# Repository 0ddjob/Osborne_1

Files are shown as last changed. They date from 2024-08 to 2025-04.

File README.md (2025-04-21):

# Osborne Model 1
## [ROMs](/ROM)
- [2732] Original Osborne BIOS vers. 1.40 (from my Osborne)
- [2732] Original Osborne BIOS vers. 1.43
- [2732] Original Osborne BIOS vers. 1.44 (latest)
- [2732] 3rd party Micro Management OZROM 1E (thanks to user [nelgin](https://forum.vcfed.org/index.php?threads/osborne-1-screen-flash.1245908/post-1400583) on VCFED Forums)
- OZROM manual (cleaned up version thanks to VCFED user booboo)
- [2764] Combined OCC v1.44 & OZROM (requires daughterboard below)
- [2716] Original Osborne character generator ROM (from my Osborne)
- [2716] Original Osborne Screen Pac BIOS Rev. A

Differences between ROM v1.4 and v1.44 include:
```
; CBOOT - added seek 10 tracks and home drive
; GKEY - fixed bell bug
; SENDEN - changed the number of retrys to NRETRY
; PSEKC - added disk head settle delay
; SELDRV - changed start up delay to 500 ms
```
### OCC v1.4 ROM
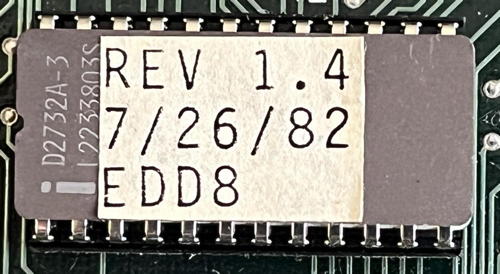
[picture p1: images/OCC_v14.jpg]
Image of OCC v1.40 ROM


### OCC Character Generator ROM
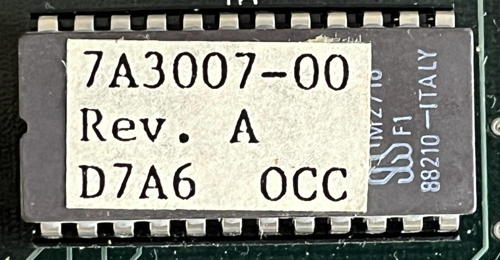
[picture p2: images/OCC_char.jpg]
Image of OCC character ROM


### Micro Management OZROM
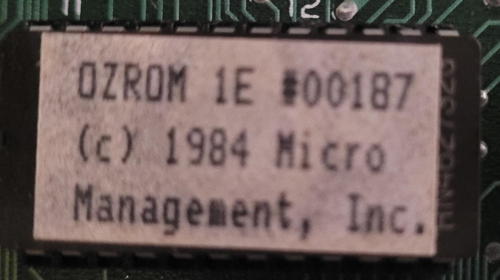
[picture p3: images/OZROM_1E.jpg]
Image of OZROM


## [Daughterboard](/2732-to-2764)
[29-Aug-2024: tested successfully]  
ROM daughterboard to accomodate 28-pin 2764 (8KByte) EPROM in the Osborne's 24-pin 2732 (4KByte) BIOS socket.  Idea is to allow switching between the official Osborne ROM and the 3rd party OZROM.  

Address pin A12 is pulled high by the 10KΩ resistor (so default is upper ROM address range 0x1000 to 0x1FFF) or can be switched to ground via a strapping or switch connected to the A12 pin header (so lower ROM address range 0x0000 to 0x0FFF).

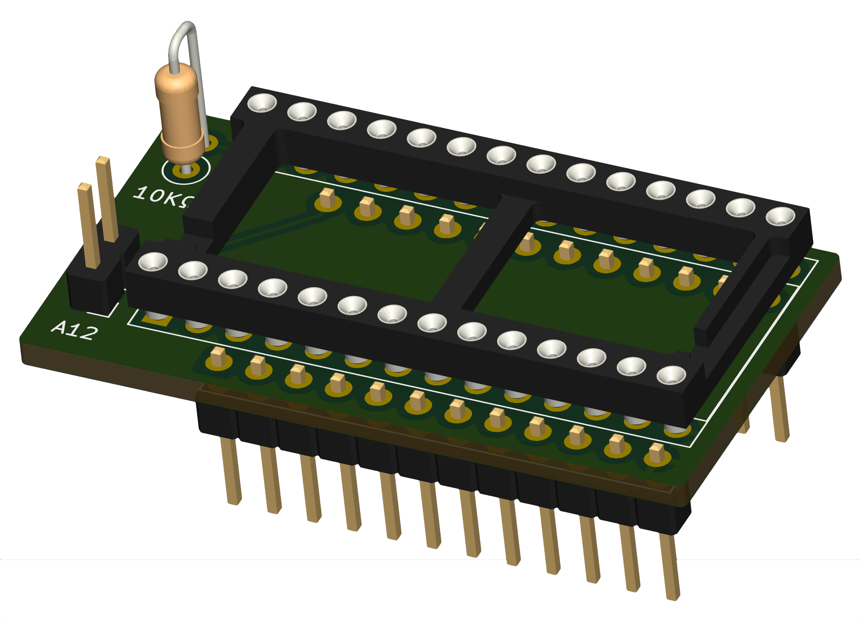
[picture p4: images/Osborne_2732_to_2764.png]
3D image of daughterboard


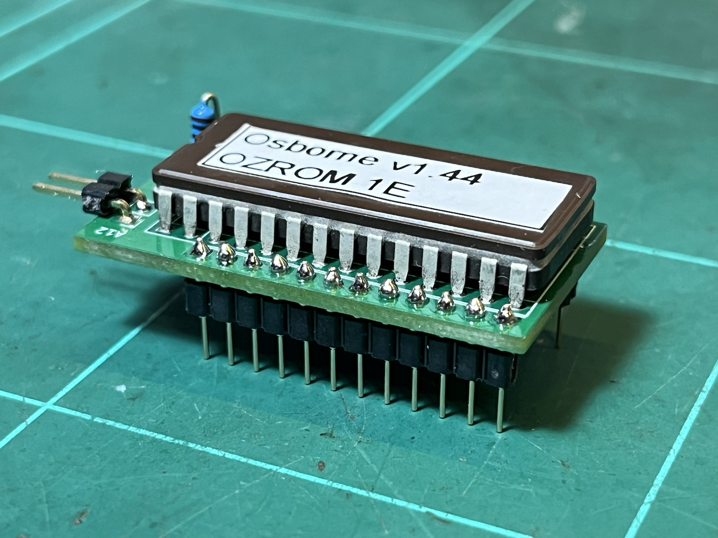
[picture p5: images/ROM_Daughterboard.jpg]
Assembled daughterboard


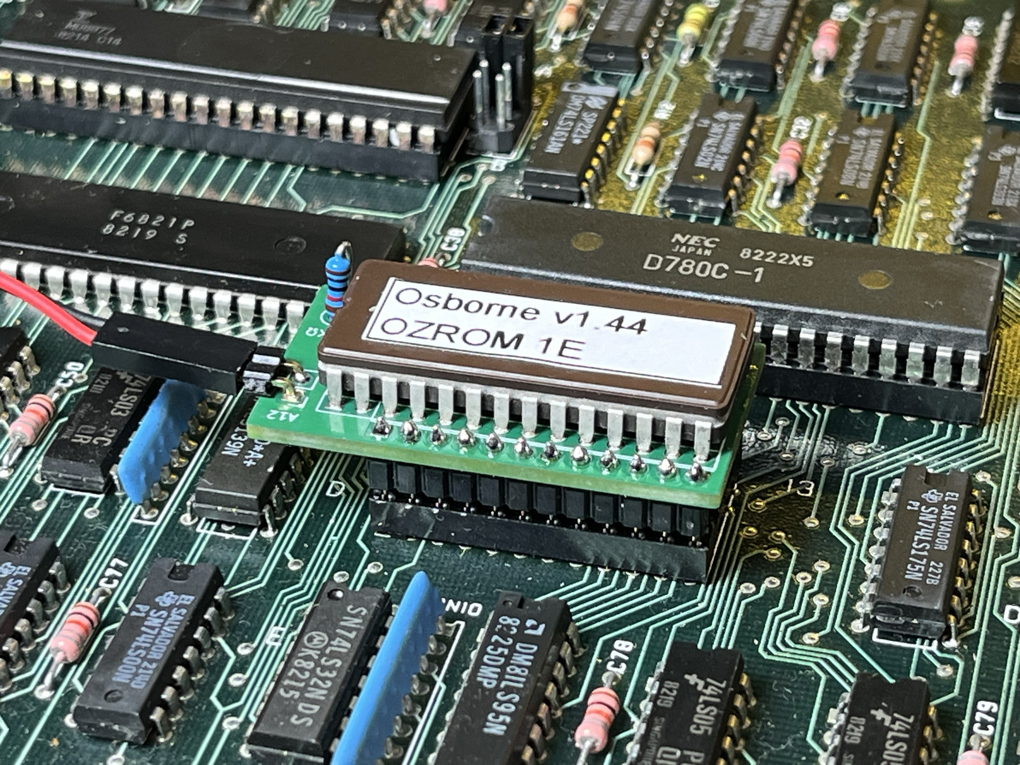
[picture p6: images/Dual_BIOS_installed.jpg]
Installed in Osborne


## [Using A Gotek](/Gotek)
Big thanks to [Dave Dunfield](http://dunfield.classiccmp.org/index.htm) for the original ImageDisk-format (IMD) disk images.

How to tell if an Osborne 1 disk image is single density (SD) or double density (DD)?

Both disk formats have 40 tracks:
* SD disks have ten 256 byte sectors per track (2560 bytes/track) -> 92KByte formatted capacity
* DD disks have five 1024 byte sectors per track (5120 bytes/track) -> 184KByte formatted capacity

Example output of ```fsed.cpm``` info command on an IMG disk image:
```
              Sector length: 1024
           Number of tracks: 40
          Sectors per track: 5
```
## [EXMON Video Output](/EXMON)
Photos of the EXMON video output shunt.

* Sullins MP-0100-10-DS-4 card edge connector
* Hyko K688-DI - this appears to combine horizontal & vertical sync with the video output, powered by +12V

Pinout of EXMON

## [Double Density Upgrade](/DD_Upgrade)
Photos of the original Osborne DD upgrade board and details of a modern reproduction board.

## [Screen Pac Upgrade](/Screen_Pac/)
Photos of the Screen Pac board.

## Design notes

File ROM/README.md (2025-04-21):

- [2716] Osborne character generator ROM (from my Osborne)
- [2716] Osborne Screen Pac BIOS Rev. A
- [2732] Osborne BIOS vers. 1.40 (from my Osborne)
- [2732] Osborne BIOS vers. 1.43 (from a DD-upgraded motherboard)
- [2732] Osborne BIOS vers. 1.44 (latest)
- [2732] 3rd Party Micro Management OZROM 1E (thanks to user [neglin](https://forum.vcfed.org/index.php?threads/osborne-1-screen-flash.1245908/post-1400583) on VCFED Forums)
- [2764] Combined OCC v1.44 & OZROM (would require a daughterboard & switch)

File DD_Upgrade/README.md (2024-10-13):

# Osborne Model 1 Double Density Upgrade
## Modern Reproduction
[Nathaniel Roach's reproduction DD board](https://gitlab.com/NRoach44/occ1-dd-upgrade)<br>
[VCFED Forum post](https://forum.vcfed.org/index.php?threads/reproduction-osborne-1-dd-upgrade-card.1239167/)

## Images of Osborne board
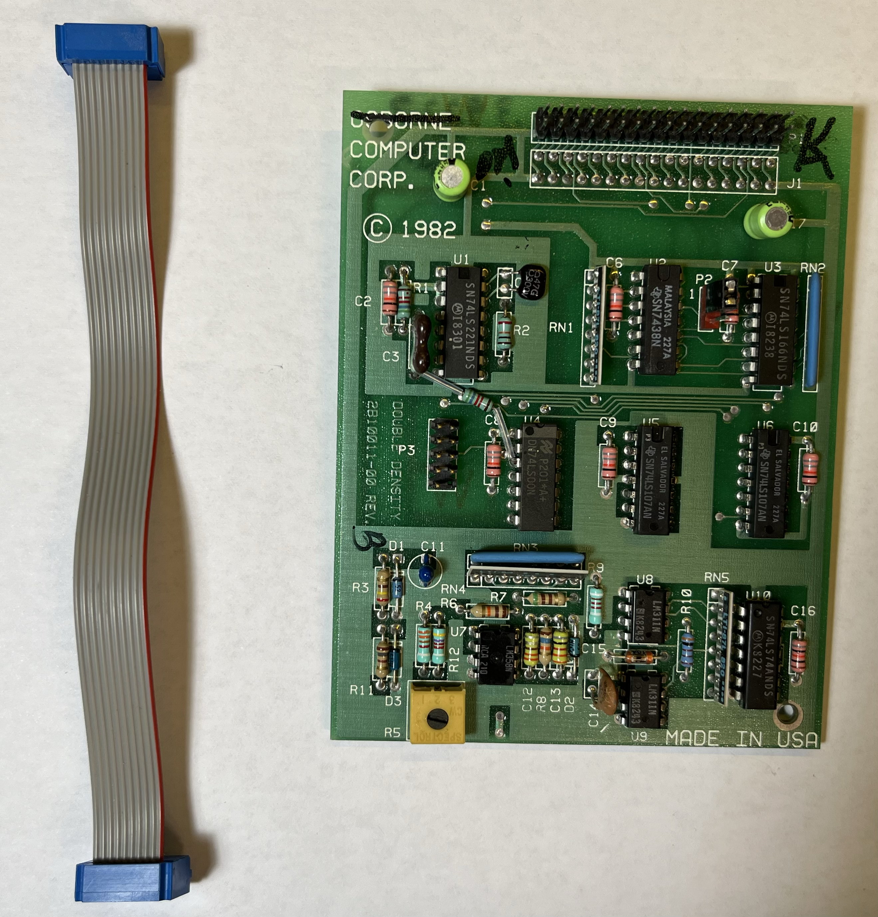
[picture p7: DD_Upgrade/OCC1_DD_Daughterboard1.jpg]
Daughterboard_1

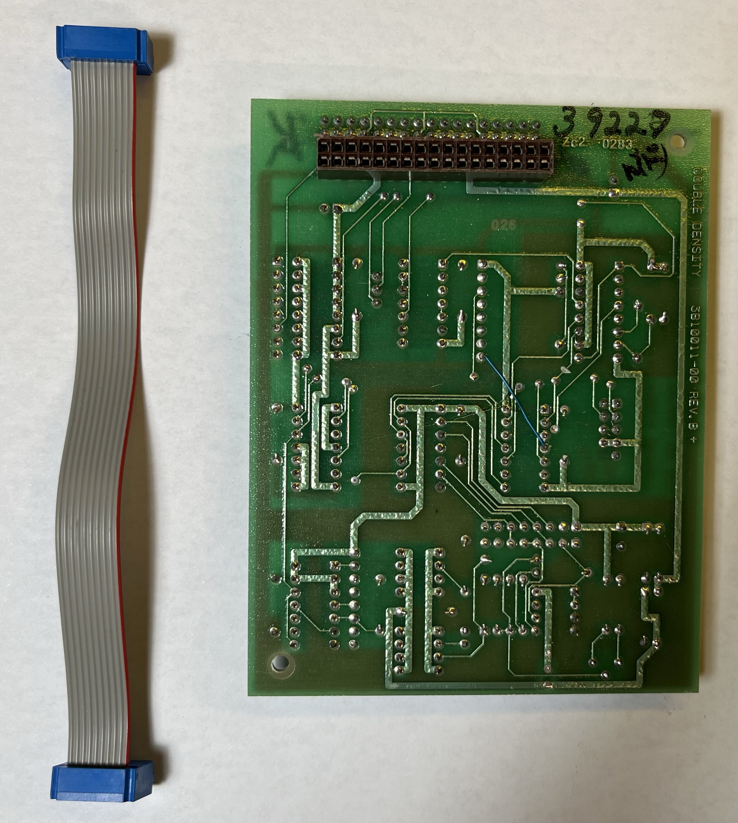
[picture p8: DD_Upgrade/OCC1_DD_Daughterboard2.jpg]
Daughterboard_2

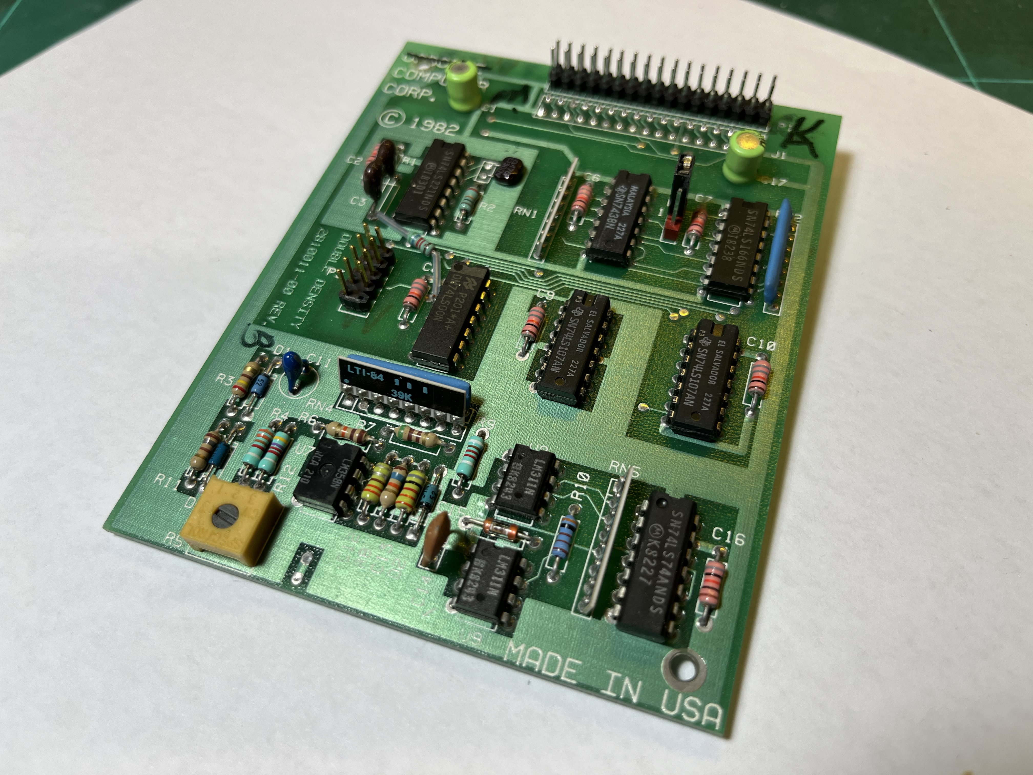
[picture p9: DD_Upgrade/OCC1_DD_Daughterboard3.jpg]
Daughterboard_3

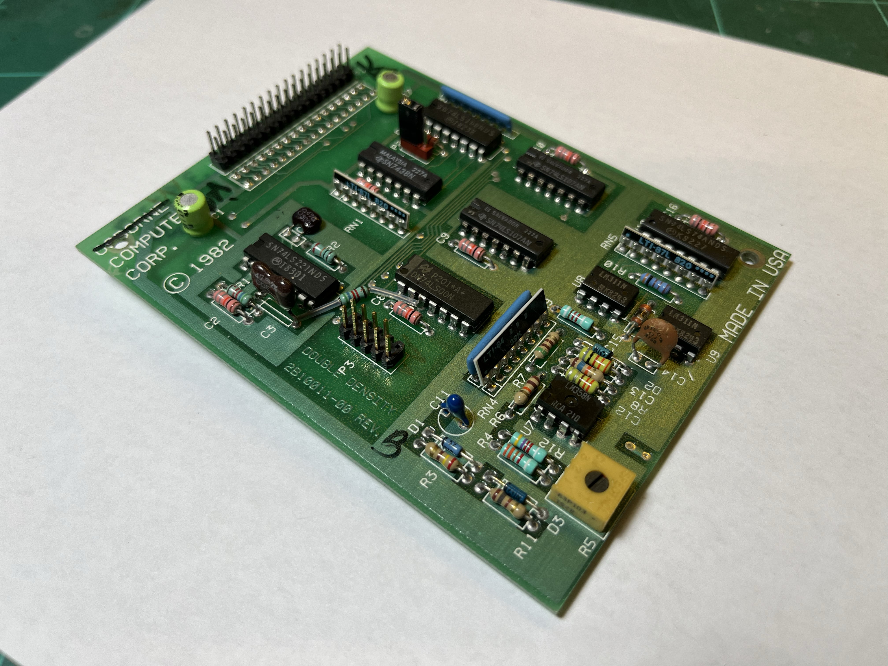
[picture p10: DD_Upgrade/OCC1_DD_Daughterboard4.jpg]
Daughterboard_4

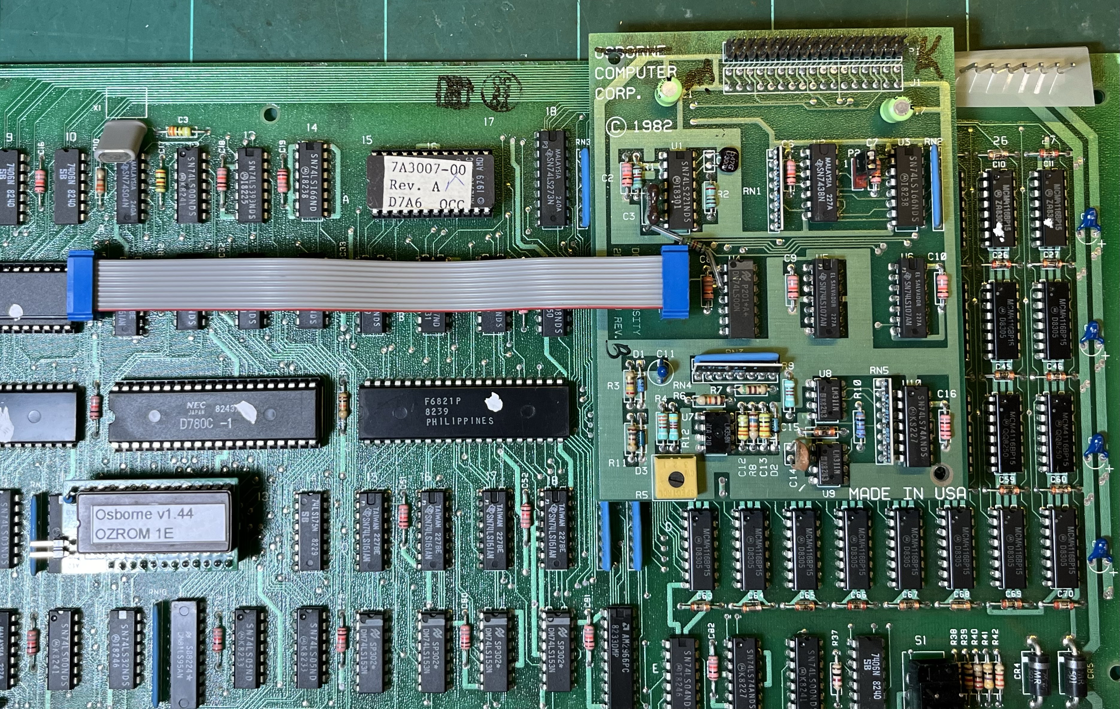
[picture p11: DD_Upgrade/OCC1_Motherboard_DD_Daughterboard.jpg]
Motherboard & Daughterboard

Note that the ribbon cable has ten wires but only eight are needed (2x4), so the cable is keyed to ensure it's installed correctly.
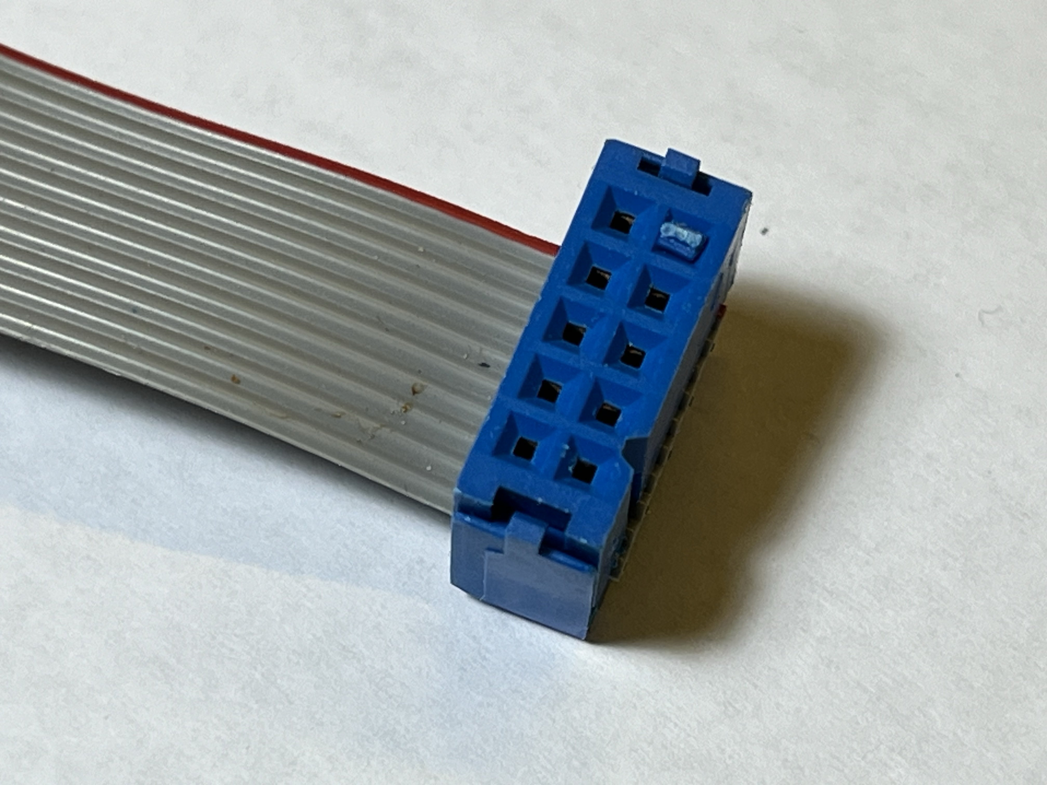
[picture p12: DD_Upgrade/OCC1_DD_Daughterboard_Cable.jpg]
Daughterboard cable


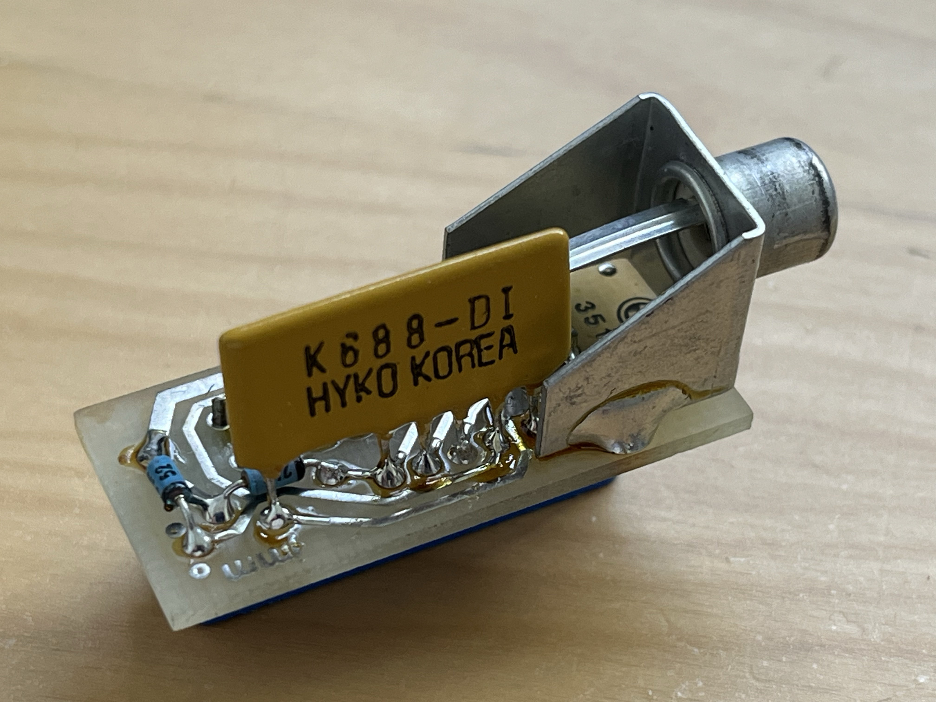
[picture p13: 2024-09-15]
EXMON/EXMON_3.jpg

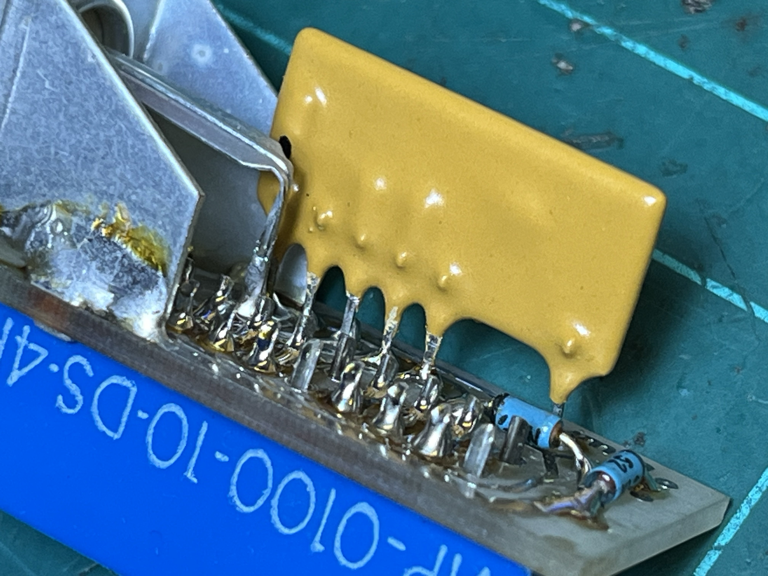
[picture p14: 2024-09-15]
EXMON/EXMON_8.jpg

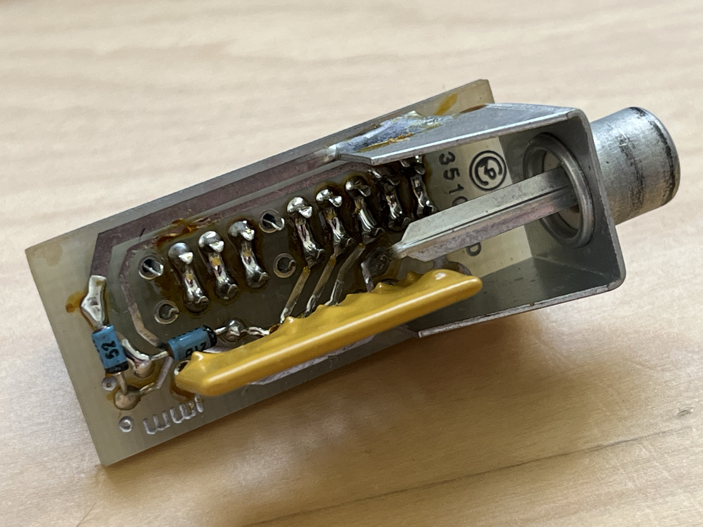
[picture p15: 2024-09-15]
EXMON/EXMON_5.jpg

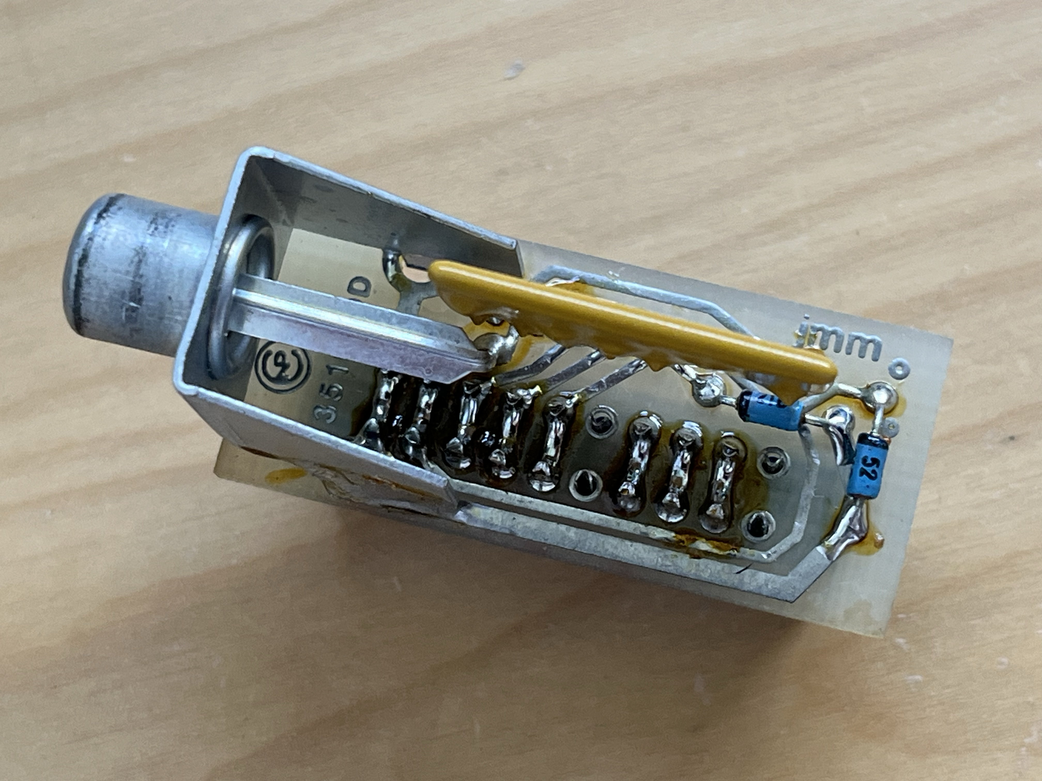
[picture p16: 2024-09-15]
EXMON/EXMON_4.jpg

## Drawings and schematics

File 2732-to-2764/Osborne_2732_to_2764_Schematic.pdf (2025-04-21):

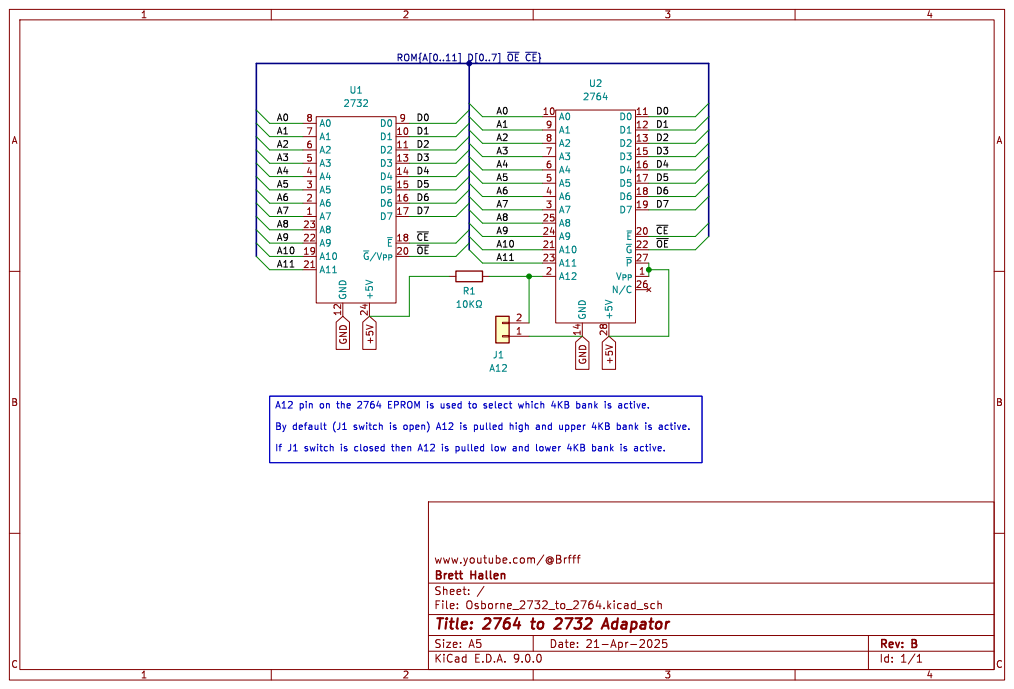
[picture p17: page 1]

If J1 switch is closed then A12 is pulled low and lower 4KB bank is active.

www.youtube.com/@Brfff
Sheet: /
File: Osborne_2732_to_2764.kicad_sch
Title: 2764 to 2732 Adapator

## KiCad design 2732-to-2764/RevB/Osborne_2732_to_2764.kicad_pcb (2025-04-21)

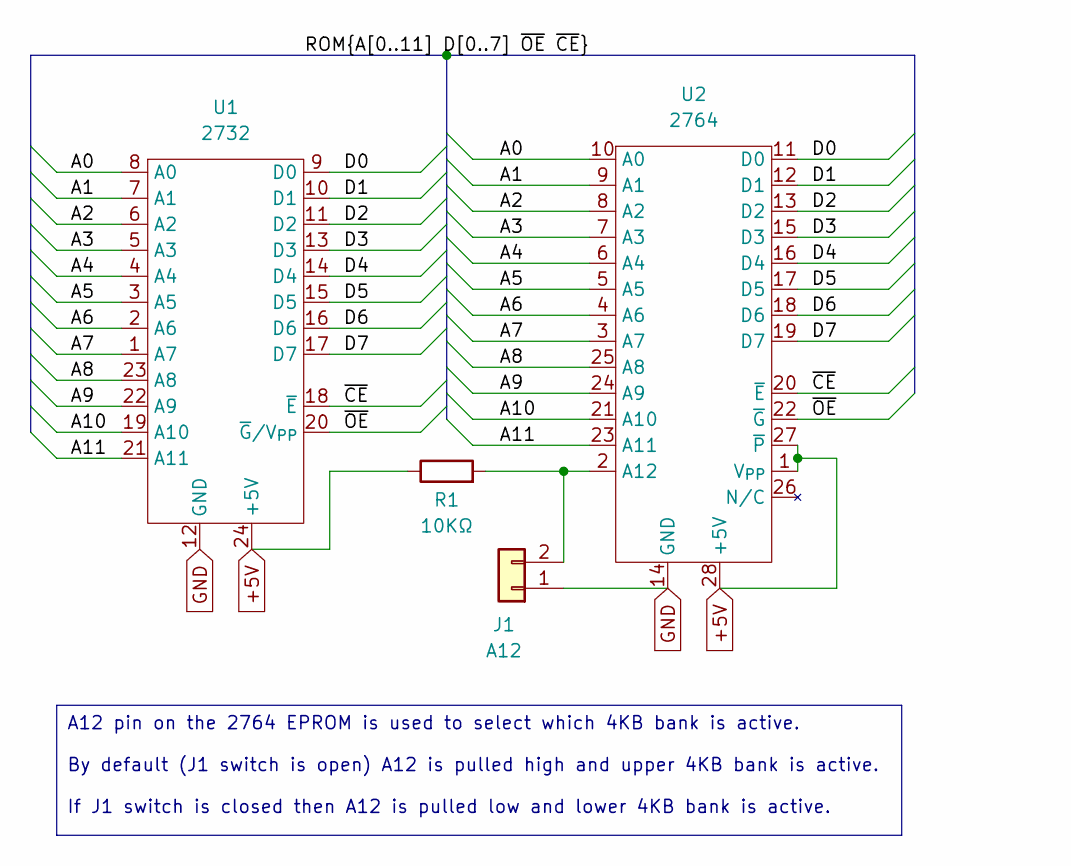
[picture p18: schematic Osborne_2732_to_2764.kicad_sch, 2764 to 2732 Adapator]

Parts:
J1: A12; PinHeader_1x02_P2.54mm_Vertical
R1: 10KΩ; R_Axial_DIN0207_L6.3mm_D2.5mm_P2.54mm_Vertical
U1: 2732; DIP-24_W15.24mm-Notch
U2: 2764; DIP-28_W15.24mm_Socket

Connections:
+5V: R1.1, U1.24 (+5V), U2.1 (V_{PP}), U2.27 (~P), U2.28 (+5V)
/A0: U1.8 (A0), U2.10 (A0)
/A1: U1.7 (A1), U2.9 (A1)
/A2: U1.6 (A2), U2.8 (A2)
/A3: U1.5 (A3), U2.7 (A3)
/A4: U1.4 (A4), U2.6 (A4)
/A5: U1.3 (A5), U2.5 (A5)
/A6: U1.2 (A6), U2.4 (A6)
/A7: U1.1 (A7), U2.3 (A7)
/A8: U1.23 (A8), U2.25 (A8)
/A9: U1.22 (A9), U2.24 (A9)
/A10: U1.19 (A10), U2.21 (A10)
/A11: U1.21 (A11), U2.23 (A11)
/D0: U1.9 (D0), U2.11 (D0)
/D1: U1.10 (D1), U2.12 (D1)
/D2: U1.11 (D2), U2.13 (D2)
/D3: U1.13 (D3), U2.15 (D3)
/D4: U1.14 (D4), U2.16 (D4)
/D5: U1.15 (D5), U2.17 (D5)
/D6: U1.16 (D6), U2.18 (D6)
/D7: U1.17 (D7), U2.19 (D7)
/~CE: U1.18 (~E), U2.20 (~E)
/~OE: U1.20 (~G/V_{PP}), U2.22 (~G)
GND: J1.1, U1.12 (GND), U2.14 (GND)
unnamed: J1.2, R1.2, U2.2 (A12)

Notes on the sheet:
A12 pin on the 2764 EPROM is used to select which 4KB bank is active. By default (J1 switch is open) A12 is pulled high and upper 4KB bank is active. If J1 switch is closed then A12 is pulled low and lower 4KB bank is active.

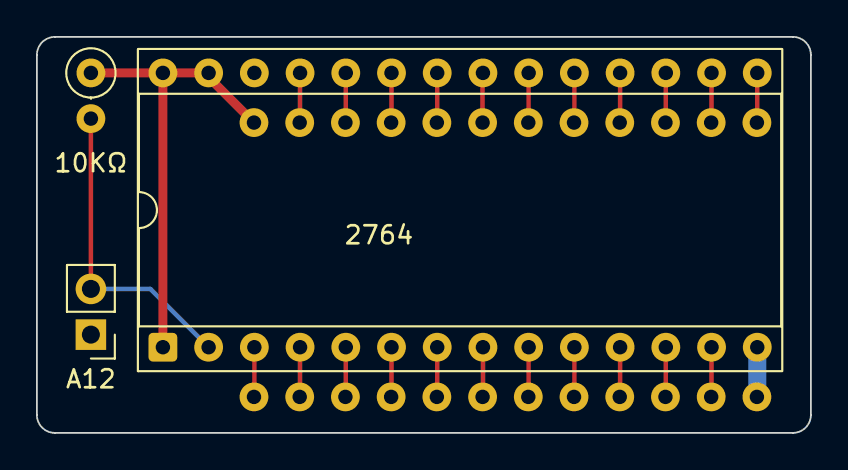
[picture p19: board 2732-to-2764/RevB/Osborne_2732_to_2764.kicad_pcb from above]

Board: 2 copper layers, 43.0 x 22.0 mm, 4 parts (0 on the bottom side), 25 nets.

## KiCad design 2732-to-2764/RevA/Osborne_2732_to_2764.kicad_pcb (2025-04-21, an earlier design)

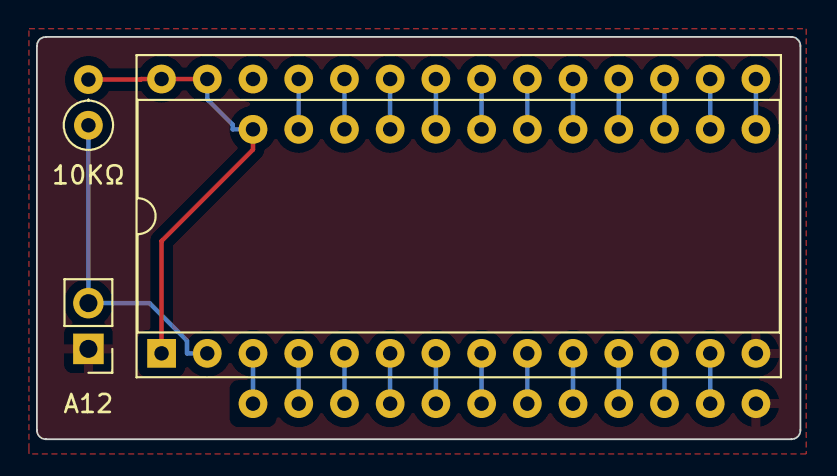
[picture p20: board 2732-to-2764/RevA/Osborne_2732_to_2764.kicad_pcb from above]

Board: 2 copper layers, 42.4 x 22.4 mm, 4 parts (0 on the bottom side), 25 nets.

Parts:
J1: 2732_ROM_Socket; DIP-24_W15.24mm-Notch
J2: 2764; DIP-28_W15.24mm_Socket
J3: A12; PinHeader_1x02_P2.54mm_Vertical
R1: 10KΩ; R_Axial_DIN0207_L6.3mm_D2.5mm_P2.54mm_Vertical

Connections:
A00: J1.8, J2.10
A01: J1.7, J2.9
A02: J1.6, J2.8
A03: J1.5, J2.7
A04: J1.4, J2.6
A05: J1.3, J2.5
A06: J1.2, J2.4
A07: J1.1, J2.3
A08: J1.23, J2.25
A09: J1.22, J2.24
A10: J1.19, J2.21
A11: J1.21, J2.23
D0: J1.9, J2.11
D1: J1.10, J2.12
D2: J1.11, J2.13
D3: J1.13, J2.15
D4: J1.14, J2.16
D5: J1.15, J2.17
D6: J1.16, J2.18
D7: J1.17, J2.19
GND: J1.12, J2.14, J3.1
unnamed: J2.2, J3.2, R1.1
VCC: J1.24, J2.1, J2.27, J2.28, R1.2
~CE: J1.18, J2.20
~OE: J1.20, J2.22

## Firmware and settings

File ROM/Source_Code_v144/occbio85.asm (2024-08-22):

 	page


; The following routines will use the IOBYTE to transfer 
; control to the appropriate device driver

CONST:
;	Returns console status

	proc
	LDK	HL,PTR_CSTAT	;Status table
	JR	GODISPCH	;Call appropriate rtn
	space 4,7
CONIN:
;	Reads input character from device

	proc
	LDK	HL,PTR_CINP	;Table of input rtns
	JR	GODISPCH
	space 4,8
CONOUT:
;	Puts output character to device
;	C contains output character

	proc
	LDK	HL,PTR_COUT	;Table of output rtns
	space 4,7
GODISPCH:
	LDK	B,1		;number of shifts required to align
				;CONSOLE field
	JR	DISPCH
	space 4,20
LIST:
;	List device character output

	proc
	LDK	HL,PINTFG	;Get printer initialiation flag
	LD	A,[HL]
	ORA	A
	JRNZ	LIST1		;Printer previously initialized

	DEC	[HL]		;Non-zero value to PINTFG
	PUSH	BC		;Save character
	INC	HL
	EX	HL,DE		;Get initialization string
	CALL	PSTR		;and print it
	POP	BC		;Restore character

LIST1: 	LDK	B,4
Š	LDK	HL,PTR_LIST	;table of list routines
	JR	DISPCH
	space	4,8
PUNCH:
;	Output to punch

	proc
	LDK	B,6
	LDK	HL,PTR_PNCH	;Punch routines
	JR	DISPCH
	space	4,8
READER:
;	Reader input

	proc
    	LDK	B,8
	LDK	HL,PTR_RDR	; reader routines
	JR	DISPCH
	space	4,14
LISTST:
;	Return the ready status for the list device.
;
;	EXIT	A = 0 (zero), list device is not ready to
;		accept another character.
;		A = FFh (255), list device is ready to accept
;		a character.

	proc
	LDK	B,4		;number of left shifts thru carry
				;to align LIST field of IOBYTE
	LDK	HL,PTR_LST	;list status routines
;	JR	DISPCH
	page

DISPCH:
;	on entry here reg B contains the left shift count
;	required to align the iobyte field to bit 1 position.
;	and reg HL contains address of select table

	proc
	LD	A,IOBYTE

DSPCH1:
	RAL
	DJNZ	DSPCH1
	ANI	6		;get select field*2
	MOV	E,A
	LDK	D,0		;DE = iobyte field * 2
	DAD	DE
	MOV	E,[HL]
Š	INC	HL
	MOV	H,[HL]		;get the routine address
	MOV	L,E		;into hl and xchange with pc
	JMP	[HL]
	PAGE

;	Dispatch Table

PTR_CSTAT:
	DW	CNST		; keyboard status
	DW	SISTAT		; serial port input status
	DW	PISTAT		; parallel input status
	DW	IEINSTAT	; status of input device on IEEE port

PTR_RDR:
PTR_CINP:
	DW	KEYINP		; get input from keyboard
	DW	SPINP		; serial port input
	DW	PARINP		; parallel input
	DW	IEINP		; ieee port input

PTR_PNCH:
PTR_COUT:
	DW	CRTOUT		; output character to crt
	DW	SPOUT 		; serial port output
	DW	PAROUT		; parallel output
	DW	IEOUT		; ieee port output

PTR_LST:
	DW	CRSTAT
	DW	SOSTAT		; serial output status
	DW	POSTAT		; parallel output status
	DW	IEOSTAT		; ieee output status

PTR_LIST:
	DW	CRTOUT
	DW	PRTOUT
	DW	PAROUT
	DW	IEOUT
	page

CNST:
;	C O N S O L   S T A T U S
;
;	This routine samples the Console status and returns the
;	following values in the A register.
;
;	EXIT	A = 0 (zero), means no character
;		currently ready to read.
;
;		A = FFh (255), means character
;		currently ready to read.

;	check if any translated keys are pending

	proc
	LD	A,COUNT
	ORA	A
	JRNZ	CNST5

;	if no xlated keys pending, check keyhit flag
Š
	LD	A,LKEY		;Get Key hit flag
	ORA	A
	RZ			;If data not available

CNST5:
	ORI	0FFh
	RET
	page

KEYINP:
; 	Gets keystroke from ROM keyboard driver.
;	Translates the codes 80h to 8fh as per table. 
;
; 	EXIT	 A = translated code in ASCII

BASVL0:	=	80h			;lowest value of translatable keys
	proc
	PUSH	IX			;Save user IX

KIN0:	CALL	AHSCRL
	LDK	HL,COUNT
	LD	A,[HL]			;get number of xlated keys
	ORA	A
	JRZ	KIN10			;if keys pending then
	LD	IX,XLTKEY		;get base address in IX reg

	LD	A,[IX+0]		;simulate LD  A,(IX+COUNT)
COUNT:	=	*-1			;to get next key from table

	INC	[HL]			;increment count

KRET:	POP	IX			;Restore user IX
	RET

KIN10:
	LDK	E,09
	CALL	ROMCD1

;	When console has returned this code will check
;	for function key and preform some translation

	CPI	80h		;function keys have value
	JRC	KRET		;80h-8dh
	CPI	8Eh		;do a shift to make pointer 
	JRNC	KRET		;into table and return if not function key
	SLA	A
	MOV	E,A
	LDK	D,0
	LDK	IX,XLTBL
	ADD	IX,DE
 	LD	L,[IX+0]
	LD	H,[IX+1]
	LD	E,[IX+2]
	LD	D,[IX+3]
	STO	DE,XLTKEY
Š	SBC	HL,DE
	MOV	A,L
	STO	A,COUNT
	JR	KIN0
        page

AHSCRL:
;	ahscrl - does auto horizontal scroll if required.

	proc
	LD	A,AHSENB
	OR	A
	RZ

	LD	HL,CURS		;get cursor
	ADD	HL,HL

;	check for cursor in home window

	LDK	A,100
	CMP	L
	JRC	RHC		;jump if cursor not in home window
	LD	A,PIAAD		;check for screen at home
	SUB	VFLO
	RZ			;screen at home
	XRA	A		;home screen
	JR	SCRL

RHC:
;	check right-hand margin

	LD	A,PIAAD		;a=horizontal screen position
	SUB	VFLO
	ADD	A,100		;window size*2 (50)
	CMP	L
	JC	:30		;move screen when cursor about to go off
				;the right hand margin
;	check left hand margin

	SUB	90
	CMP	L		;check left margin
	RC			;cursor in window return
	MOV	A,L
	SUB	10
	RZ			;return if cusor at column 2
	JR	SCRL

:30:	MOV	A,L
	SUB	100

SCRL:	RAR
	ADD	A,' '
	LK	HL,ESCSQ+3
	STO	A,[HL]
	LD	A,PIABD
	AND	1Fh
	ADD	A,' '
	DEC	HL
	STO	A,[HL]			;escsq+2 = vert. coords
	DEC	HL
	DEC	HL			;point to start of esc seq
	LK	B,4

:50:	PUSH	BC
Š	PUSH	HL
	LD	C,[HL]
	CALL	CRT10
	POP	HL
	POP	BC
	INC	HL
	DJNZ	:50	
	RET	

ESCSQ:	DB	ESC			;set screen coord escape sequence
	DB	'S'
	DB	0			;** y coord
	DB	0			;** x coord
	page

CRSTAT:
;	Returns status of crt.
;	crt is always ready

	proc
	ORI	0FFh
	RET
	space	4,10
CRTOUT:
;	ENTRY	 C = output character

EF_ESC:	=	8		;escape flag bit definitions
EF_GR:	=	1

	proc
	LD	A,ESCH
	AND	EF_ESC+EF_GR
	JRNZ	CRT10
	MOV	A,C
	CPI	14h
	JRNZ	CRT10
	LD	A,AHSENB
	CMA
	STO	A,AHSENB
	RET

CRT10:
	LDK	E,0Ch		  ;output to crt
	JMP	ROMCD1
	page

SOSTAT:
;	Gets status of output device attached to serial port

	proc
	LDK	E,2Dh
	JR	JMPROM		;Call rom driver
	space 4,8
SISTAT:
;	Gets status of input device attached to serial port

	proc
	CALL	ACISTAT
	ANI	SI.RRDY
	RZ			;return with not ready status
	ORI	TRUE
	RET
	space 4,8
SPINP:
;	Inputs a character from the serial port 

	proc
	LDK	E,15h
	JR	JMPROM
	space 4,8
SPOUT:
;	Outputs character in reg c to the serial port (list device)

	proc
	LDK	E,0Fh
	JR	JMPROM
	page

PRTOUT:
;	routine does LIST output and printer protocols

XON:	=	11h
XOFF:	=	13h
ETX:	=	3
ACK:	=	6

	proc
	CALL	SPOUT
	LD	A,PRNTER
	ORA	A
	RZ
	ANI	2
	JRNZ	XONXOF
	LDK	A,0Dh
	CMP	C
	RNZ

	LDK	C,ETX
	CALL	SPOUT

PRT10:
	CALL	SPINP
	ANI	7Fh		;mask out parity bit
	CPI	ACK
	JRNZ	PRT10
	RET

XONXOF:
	CALL	SISTAT
	ORA	A
	RZ
	CALL	SPINP
	ANI	7Fh		;mask out parity bit
	CPI	XOFF
	RNZ

PRT20:
	CALL	SPINP
	ANI	7Fh		;mask out parity bit
	CPI	XON
	JRNZ	PRT20
	RET
	PAGE

JMPROM:	JMP	ROMCD1
	space	4,10
ACICTL:	=	SBAUD
;	Outputs character in c to the ACIA CTL port.
	space	4,10
ACISTAT:
;	Returns usart status in A
	
	PROC
	LDK	E,81H		;Low order byte of ACISTAT routine in ROM
	JR	JMPROM	
	page
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

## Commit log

2024-08-19 Added FF configuration files for simplicity
    [FF.CFG, IMG.CFG]
2024-08-19 Intial 2764 adaptor design
    [Osborne_2732_to_2764.kicad_pcb, Osborne_2732_to_2764.kicad_sch]
2024-08-19 Corrected subdirectory name
    [Osborne_2732_to_2764.kicad_pcb, Osborne_2732_to_2764.kicad_sch]
2024-08-19 Updated silkscreen
    [Osborne_2732_to_2764.kicad_pcb]
2024-08-21 Corrected Gerbers for PCBWAY (still pending testing)
    [Osborne_2732_to_2764.kicad_pcb]
2024-08-23 Updated socket pins
    [Osborne_2732_to_2764.kicad_pcb, Osborne_2732_to_2764.kicad_sch]
2024-09-15 Soldered EPROM directly to daughterboard
2024-09-15 Further device detail
2024-11-25 Updated to Kicad 8.0.6
    [Osborne_2732_to_2764.kicad_pcb, Osborne_2732_to_2764.kicad_sch]
2025-04-21 Redrew/improved schematic
    Created symbols for the 2732 & 2764 EPROMs and used busses to connect.
    PCB is roughly identical - connections are all the same but I manually doubled 5V rail track width
    [Osborne_2732_to_2764.kicad_pcb, Osborne_2732_to_2764.kicad_sch]
